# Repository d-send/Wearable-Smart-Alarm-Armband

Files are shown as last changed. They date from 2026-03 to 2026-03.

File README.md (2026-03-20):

# Wearable Smart Alarm Armband (Work in progress)

An Armband designed primaraly for force waking up in the morning using vibration and Electrical stimulation.Uses an android app to communicate via BLE for scheuling and monitering status such as battery capacity.Integrated IMU is used to detect weather the user is awake or sleeping.

## Features
* Wakeup sheduling capability through an android app via BLE
* reminders through vibrations
* two hardware buttons for additional functionalities
* extremely low power consumption
* detachable battery
* tightness adjestable strip (around arm)  

## PCB
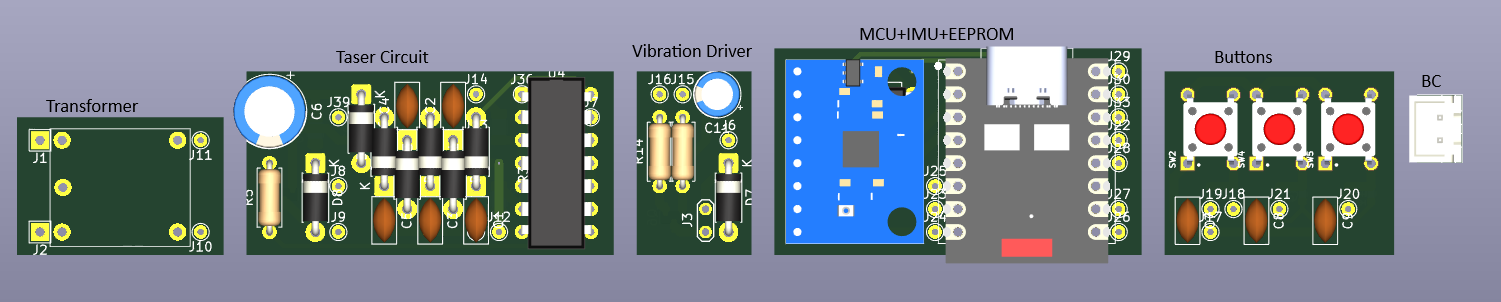
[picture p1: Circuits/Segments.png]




## Finished Armband 
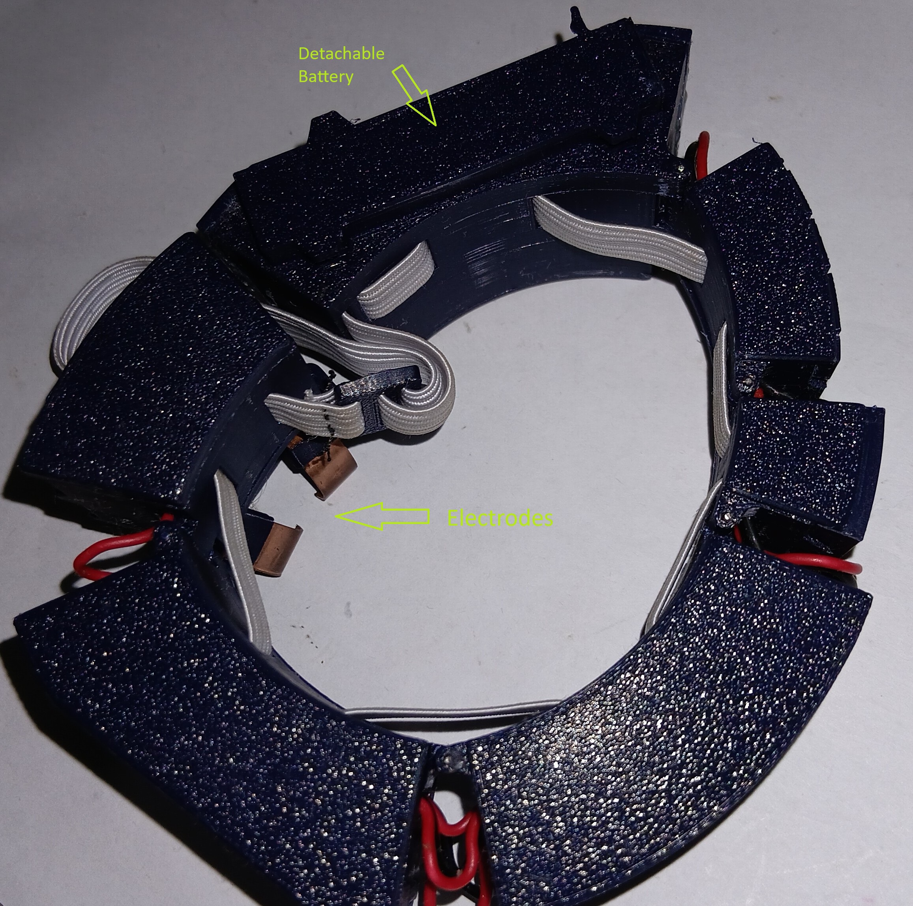
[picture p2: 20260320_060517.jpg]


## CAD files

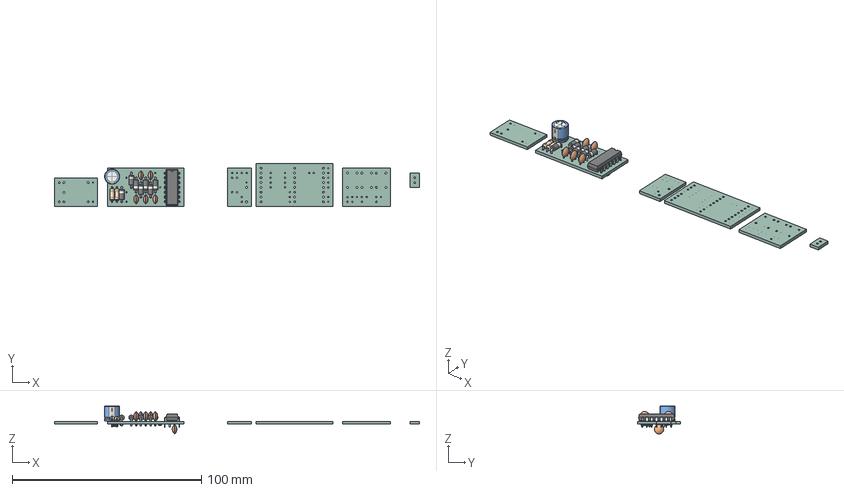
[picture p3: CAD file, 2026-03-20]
Circuits/PCB/Tazer.step
193.0 x 22.9 x 14.8 mm
C_Disc_D5.0mm_W2.5mm_P2.50mm x 6
D_DO-41_SOD81_P7.62mm_Horizontal x 7
R_Axial_DIN0207_L6.3mm_D2.5mm_P7.62mm_Horizontal x 3
DIP-14_W7.62mm
CP_Radial_D8.0mm_P3.80mm
SOT-23
R_1206_3216Metric x 3
R_0603_1608Metric x 2
PCB_V6_PCB_1
PCB_V6_PCB_2
PCB_V6_PCB_3
PCB_V6_PCB_4
PCB_V6_PCB_5
PCB_V6_PCB_6

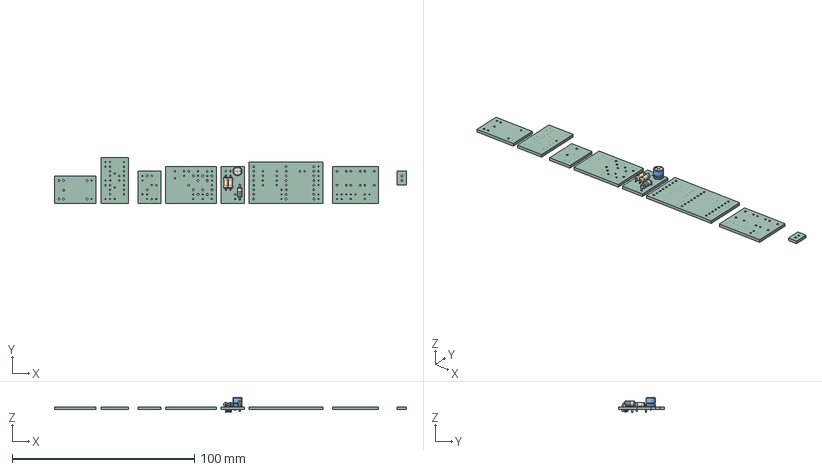
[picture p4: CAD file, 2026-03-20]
Circuits/PCB/VIB_DRIVER.step
193.0 x 25.4 x 8.00 mm
D_DO-41_SOD81_P7.62mm_Horizontal
R_Axial_DIN0207_L6.3mm_D2.5mm_P7.62mm_Horizontal x 2
CP_Radial_D5.0mm_P2.50mm
SOT-23
PCB_V6_PCB_1
PCB_V6_PCB_2
PCB_V6_PCB_3
PCB_V6_PCB_4
PCB_V6_PCB_5
PCB_V6_PCB_6
PCB_V6_PCB_7
PCB_V6_PCB_8

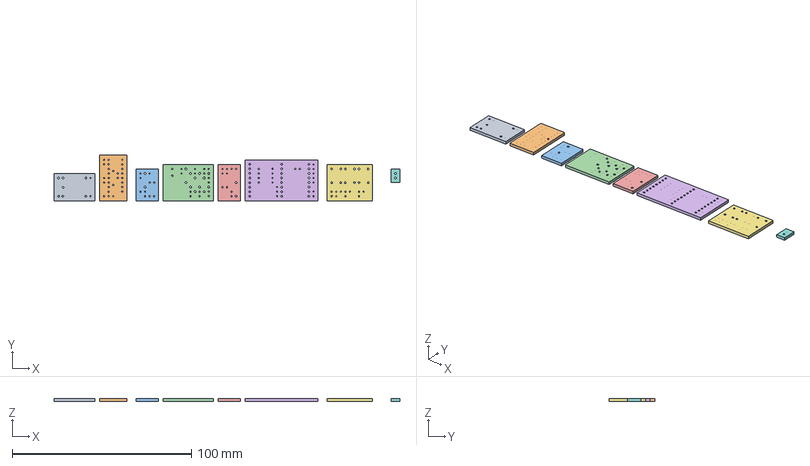
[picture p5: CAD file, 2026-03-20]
Circuits/PCB/Flyback_Transformer.step
193.0 x 25.4 x 1.51 mm
PCB_V6_PCB_1
PCB_V6_PCB_2
PCB_V6_PCB_3
PCB_V6_PCB_4
PCB_V6_PCB_5
PCB_V6_PCB_6
PCB_V6_PCB_7
PCB_V6_PCB_8

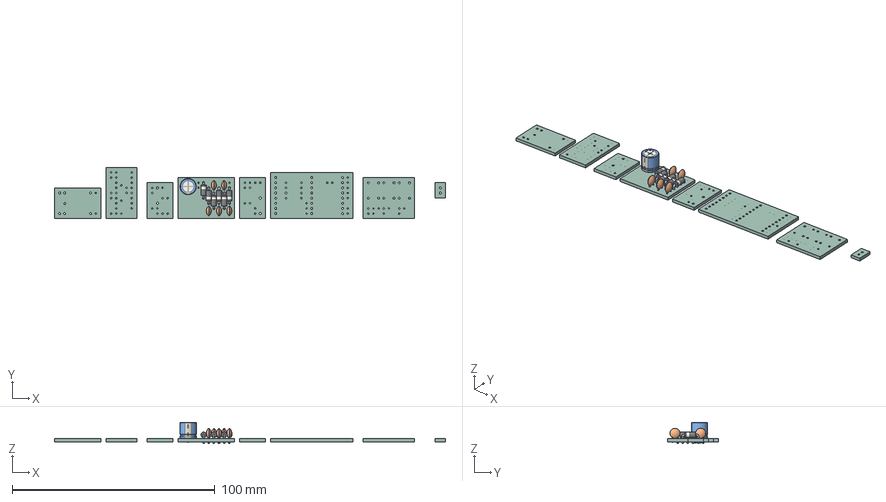
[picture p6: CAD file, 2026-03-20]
Circuits/PCB/Tazer_Charger.step
193.0 x 25.4 x 10.5 mm
C_Disc_D5.0mm_W2.5mm_P2.50mm x 5
D_DO-41_SOD81_P7.62mm_Horizontal x 6
CP_Radial_D8.0mm_P3.80mm
R_0603_1608Metric x 2
PCB_V6_PCB_1
PCB_V6_PCB_2
PCB_V6_PCB_3
PCB_V6_PCB_4
PCB_V6_PCB_5
PCB_V6_PCB_6
PCB_V6_PCB_7
PCB_V6_PCB_8

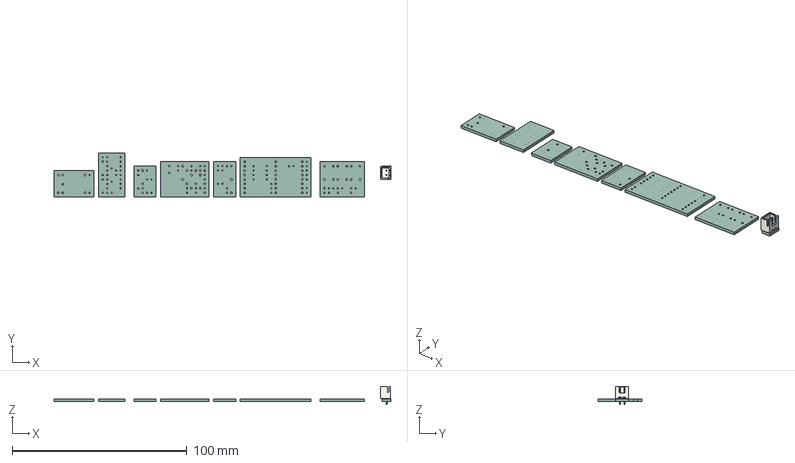
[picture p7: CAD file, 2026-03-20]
Circuits/PCB/Bat_Connector.step
193.0 x 25.4 x 10.4 mm
JST_XH_B2B-XH-A_1x02_P2.50mm_Vertical
PCB_V6_PCB_1
PCB_V6_PCB_2
PCB_V6_PCB_3
PCB_V6_PCB_4
PCB_V6_PCB_5
PCB_V6_PCB_6
PCB_V6_PCB_7
PCB_V6_PCB_8

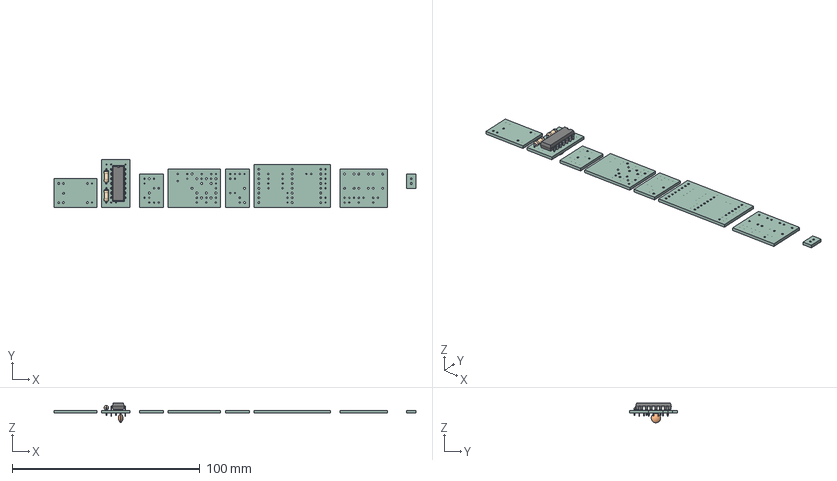
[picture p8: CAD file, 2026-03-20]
Circuits/PCB/Inverter.step
193.0 x 25.4 x 10.5 mm
R_Axial_DIN0207_L6.3mm_D2.5mm_P7.62mm_Horizontal x 3
DIP-14_W7.62mm
C_Disc_D5.0mm_W2.5mm_P2.50mm
PCB_V6_PCB_1
PCB_V6_PCB_2
PCB_V6_PCB_3
PCB_V6_PCB_4
PCB_V6_PCB_5
PCB_V6_PCB_6
PCB_V6_PCB_7
PCB_V6_PCB_8

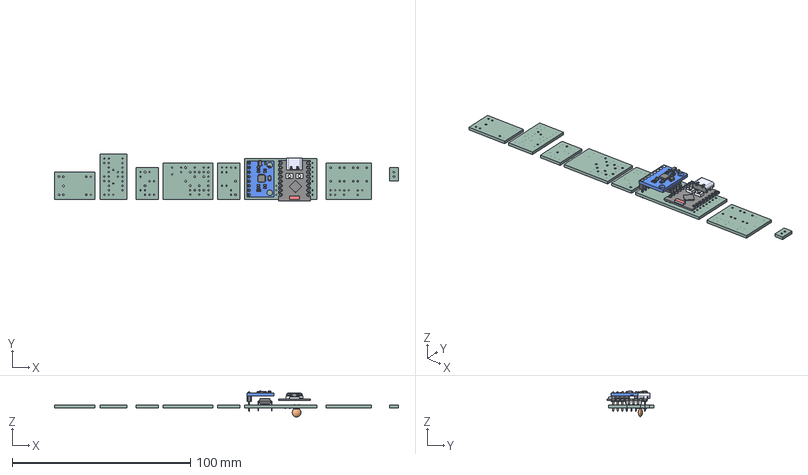
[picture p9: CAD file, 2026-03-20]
Circuits/PCB/MCU_EEPROM.step
193.0 x 26.3 x 14.6 mm
Board_001
SOT25_001
0603 Capacitor_001
0603 Capacitor_002
0603 Capacitor_003
0603 Capacitor_004
0603 Capacitor_005
0603 Capacitor_006
0603 Resistor_001
0603 Resistor_002
0603 Resistor_003
0603 Resistor_004
SM LED_001
Diode 2_001
24 QFN_001
1x8 Male Header_001
DIP-8_W7.62mm
Board c3mini
USB C
components (other)^ESP32-C3 SuperMini
R_0603_1608Metric x 2
R_1206_3216Metric x 2
C_Disc_D5.0mm_W2.5mm_P2.50mm
PCB_V6_PCB_1
PCB_V6_PCB_2
PCB_V6_PCB_3
PCB_V6_PCB_4
PCB_V6_PCB_5
PCB_V6_PCB_6
PCB_V6_PCB_7
PCB_V6_PCB_8

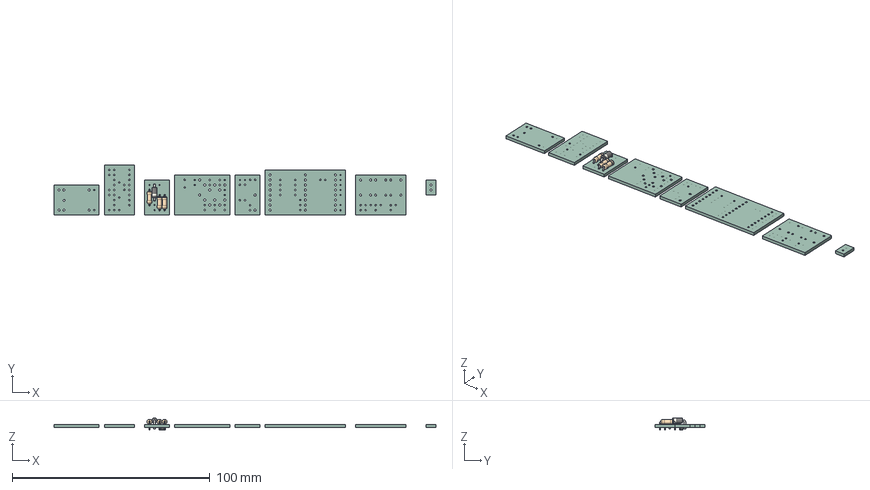
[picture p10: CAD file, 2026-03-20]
Circuits/PCB/Tazer_Discharger.step
193.0 x 25.4 x 6.21 mm
D_DO-41_SOD81_P7.62mm_Horizontal
R_Axial_DIN0207_L6.3mm_D2.5mm_P7.62mm_Horizontal x 3
SOT-23
PCB_V6_PCB_1
PCB_V6_PCB_2
PCB_V6_PCB_3
PCB_V6_PCB_4
PCB_V6_PCB_5
PCB_V6_PCB_6
PCB_V6_PCB_7
PCB_V6_PCB_8

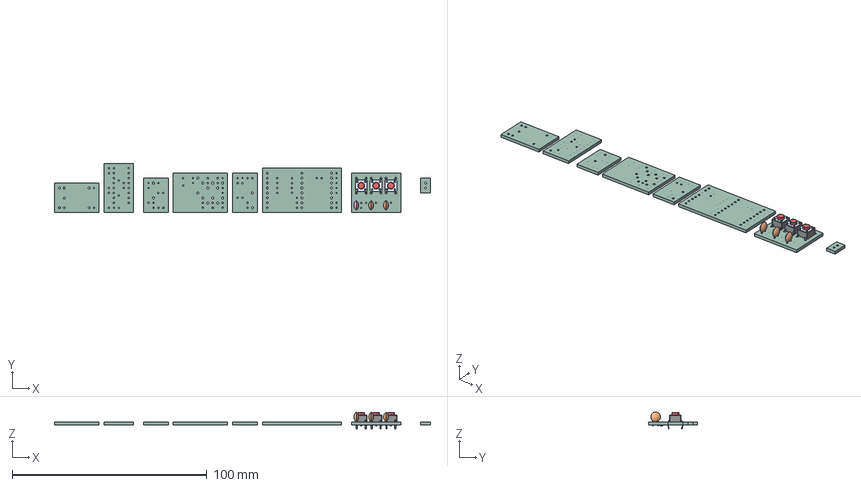
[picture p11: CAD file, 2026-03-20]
Circuits/PCB/Buttons.step
193.0 x 25.4 x 8.61 mm
1825910-6--3DModel-STEP-418109 x 3
C_Disc_D5.0mm_W2.5mm_P2.50mm x 3
R_0603_1608Metric x 6
PCB_V6_PCB_1
PCB_V6_PCB_2
PCB_V6_PCB_3
PCB_V6_PCB_4
PCB_V6_PCB_5
PCB_V6_PCB_6
PCB_V6_PCB_7
PCB_V6_PCB_8

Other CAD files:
Fusion Files/BatteryConnector_Finished.f3d
Fusion Files/Buttons_Finished.f3d
Fusion Files/MCU_Finished.f3d
Fusion Files/MainHousings.f3d
Fusion Files/Tazer_Finished.f3d
Fusion Files/Transformer_Finised.f3d
Fusion Files/Vib_Driver_Finished.f3d

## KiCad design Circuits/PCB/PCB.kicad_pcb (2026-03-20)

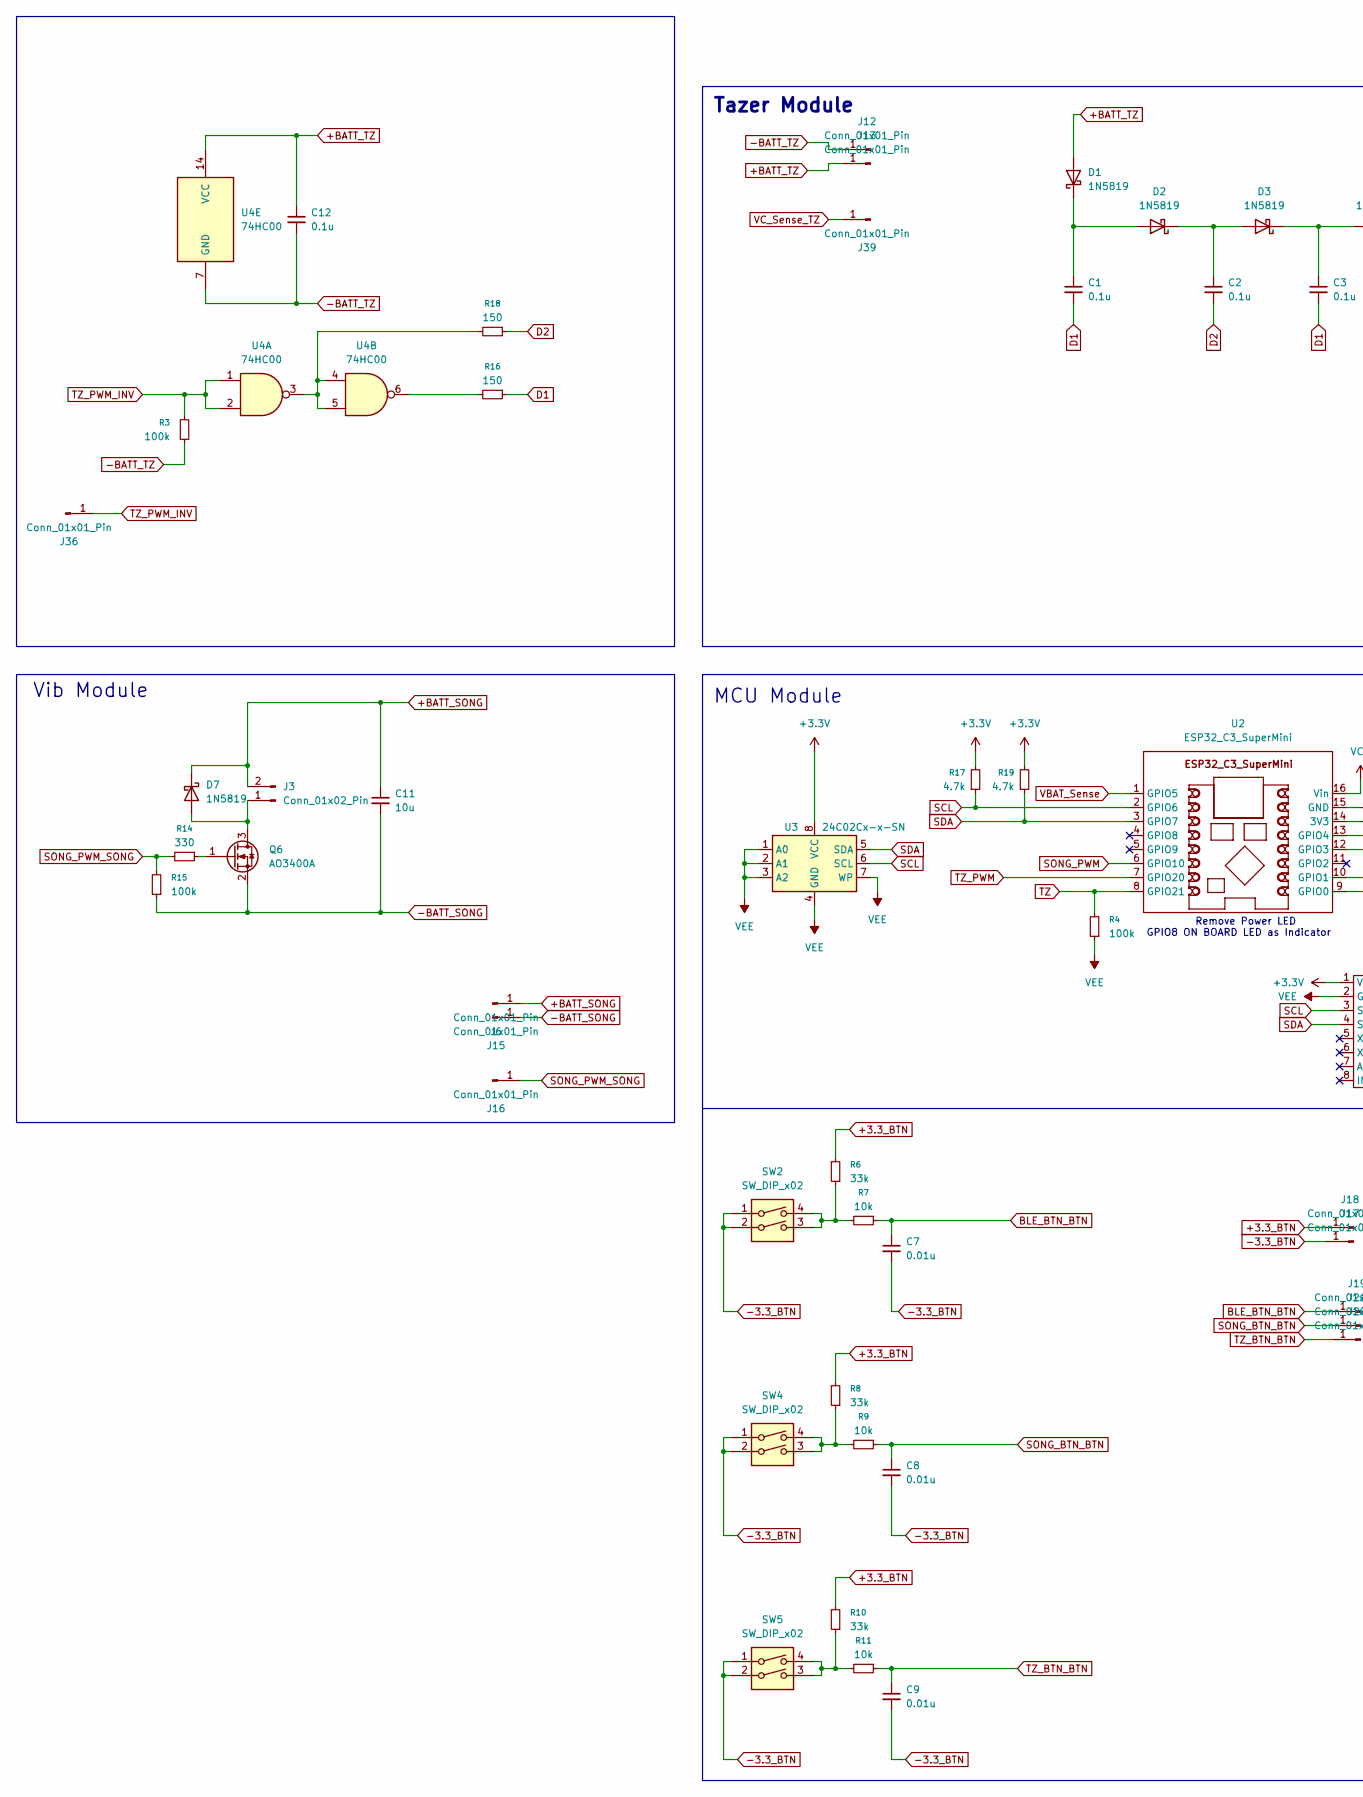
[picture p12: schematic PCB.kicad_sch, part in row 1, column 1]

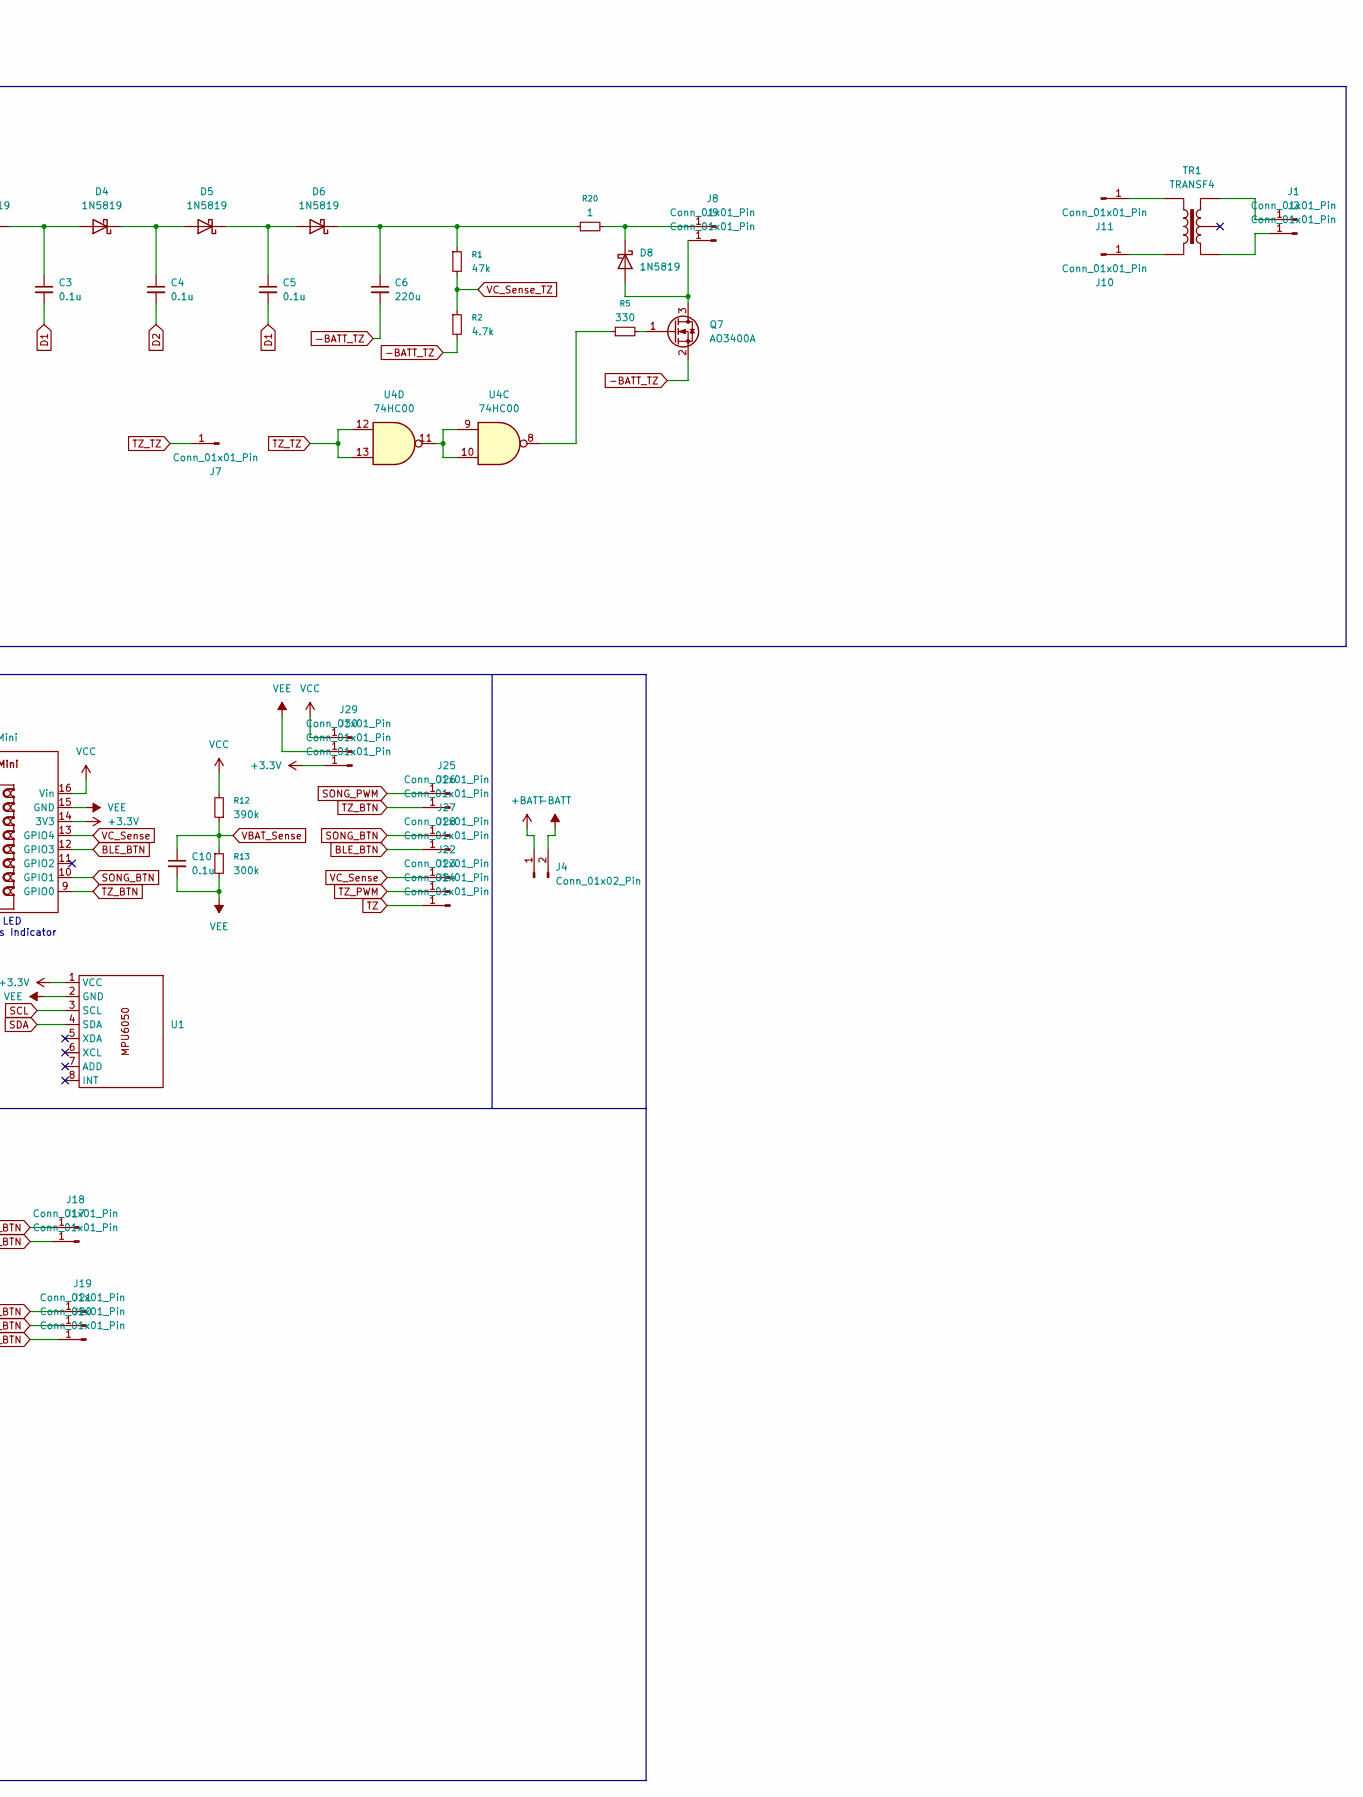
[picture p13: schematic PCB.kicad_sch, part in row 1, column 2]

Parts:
C1, C2, C3, C4, C5, C10, C12: 0.1u; C_Disc_D5.0mm_W2.5mm_P2.50mm
C6: 220u; CP_Radial_D8.0mm_P3.80mm
C7, C8, C9: 0.01u; C_Disc_D5.0mm_W2.5mm_P2.50mm
C11: 10u; CP_Radial_D5.0mm_P2.50mm
D1, D2, D3, D4, D5, D6, D7, D8: 1N5819; D_DO-41_SOD81_P7.62mm_Horizontal
J1, J2: Conn_01x01_Pin; TestPoint_THTPad_2.0x2.0mm_Drill1.0mm
J3: Conn_01x02_Pin; TestPoint_2Pads_Pitch2.54mm_Drill0.8mm
J4: Conn_01x02_Pin; JST_XH_B2B-XH-A_1x02_P2.50mm_Vertical
J6, J7, J8, J9, J10, J11, J12, J13, J15, J16, J17, J18, J19, J20, J21, J22, J23, J24, J25, J26, J27, J28, J29, J30, J33, J36, J39: Conn_01x01_Pin; TestPoint_THTPad_D1.5mm_Drill0.7mm
Q6, Q7: AO3400A; SOT-23
R1: 47k; R_0603_1608Metric
R2, R17, R19: 4.7k; R_0603_1608Metric
R3, R15: 100k; R_Axial_DIN0207_L6.3mm_D2.5mm_P7.62mm_Horizontal
R4: 100k; R_Axial_DIN0207_L6.3mm_D2.5mm_P10.16mm_Horizontal
R5, R14: 330; R_Axial_DIN0207_L6.3mm_D2.5mm_P7.62mm_Horizontal
R6, R8, R10: 33k; R_0603_1608Metric
R7, R9, R11: 10k; R_0603_1608Metric
R12: 390k; R_1206_3216Metric
R13: 300k; R_1206_3216Metric
R16, R18: 150; R_1206_3216Metric
R20: 1; R_1206_3216Metric
SW2, SW4, SW5: SW_DIP_x02; DPDT_Switch
TR1: TRANSF4; 5pin Flyback Transformer
U1: MPU6050_Module
U2: ESP32_C3_SuperMini
U3: 24C02Cx-x-SN; DIP-8_W7.62mm
U4: 74HC00; DIP-14_W7.62mm

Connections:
+3.3V: J33.1, R17.2, R19.2, U1.1 (VCC), U2.14 (3V3), U3.8 (VCC)
+3.3_BTN: J18.1, R6.2, R8.2, R10.2
+BATT: J4.1
+BATT_SONG: C11.1, D7.1 (K), J3.2, J6.1
+BATT_TZ: C12.1, D1.2 (A), J13.1, U4.14 (VCC)
-3.3_BTN: C7.2, C8.2, C9.2, J17.1, SW2.1, SW2.2, SW4.1, SW4.2, SW5.1, SW5.2
-BATT: J4.2
-BATT_SONG: C11.2, J15.1, Q6.2 (S), R15.1
-BATT_TZ: C6.2, C12.2, J12.1, Q7.2 (S), R2.2, R3.1, U4.7 (GND)
BLE_BTN: J28.1, U2.12 (GPIO3)
BLE_BTN_BTN: C7.1, J19.1, R7.1
D1: C1.2, C3.2, C5.2, R16.1; also elsewhere on the board
D2: C2.2, C4.2, R18.1; also elsewhere on the board
unnamed: C1.1, D1.1 (K), D2.2 (A)
unnamed: C2.1, D2.1 (K), D3.2 (A)
unnamed: C3.1, D3.1 (K), D4.2 (A)
unnamed: C4.1, D4.1 (K), D5.2 (A)
unnamed: C5.1, D5.1 (K), D6.2 (A)
unnamed: C6.1, D6.1 (K), R1.1, R20.1
unnamed: D7.2 (A), J3.1, Q6.3 (D)
unnamed: D8.2 (A), J9.1, Q7.3 (D)
unnamed: D8.1 (K), J8.1, R20.2
unnamed: J1.1, TR1.3
unnamed: J2.1, TR1.1
unnamed: J10.1, TR1.5
unnamed: J11.1, TR1.4
unnamed: Q6.1 (G), R14.1
unnamed: Q7.1 (G), R5.2
unnamed: R5.1, U4.8
unnamed: R6.1, R7.2, SW2.3, SW2.4
unnamed: R8.1, R9.2, SW4.3, SW4.4
unnamed: R10.1, R11.2, SW5.3, SW5.4
unnamed: R16.2, U4.6
unnamed: R18.2, U4.3, U4.4, U4.5
unnamed: U4.9, U4.10, U4.11
SCL: R17.1, U1.3 (SCL), U2.2 (GPIO6), U3.6 (SCL)
SDA: R19.1, U1.4 (SDA), U2.3 (GPIO7), U3.5 (SDA)
SONG_BTN: J27.1, U2.10 (GPIO1)
SONG_BTN_BTN: C8.1, J21.1, R9.1
SONG_PWM: J25.1, U2.6 (GPIO10)
SONG_PWM_SONG: J16.1, R14.2, R15.2
TZ: J24.1, R4.2, U2.8 (GPIO21)
TZ_BTN: J26.1, U2.9 (GPIO0)
TZ_BTN_BTN: C9.1, J20.1, R11.1
TZ_PWM: J23.1, U2.7 (GPIO20)
TZ_PWM_INV: J36.1, R3.2, U4.1, U4.2
TZ_TZ: J7.1, U4.12, U4.13
VBAT_Sense: C10.1, R12.1, R13.1, U2.1 (GPIO5)
VCC: J29.1, R12.2, U2.16 (Vin)
VC_Sense: J22.1, U2.13 (GPIO4)
VC_Sense_TZ: J39.1, R1.2, R2.1
VEE: C10.2, J30.1, R4.1, R13.2, U1.2 (GND), U2.15 (GND), U3.1 (A0), U3.2 (A1), U3.3 (A2), U3.4 (GND), U3.7 (WP)

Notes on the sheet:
GPIO8 ON BOARD LED as Indicator
Remove Power LED
MCU Module
Vib Module
Tazer Module

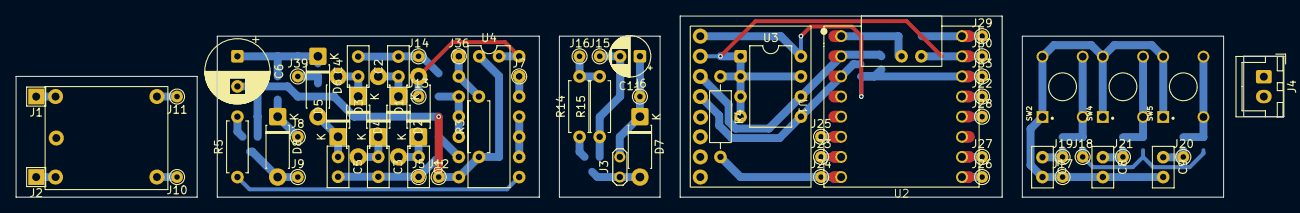
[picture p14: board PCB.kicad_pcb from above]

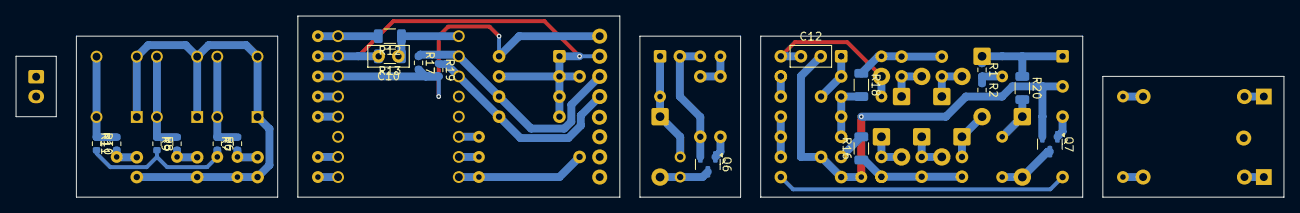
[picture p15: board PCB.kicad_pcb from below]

Board: 2 copper layers, 160.0 x 22.9 mm, 83 parts (19 on the bottom side), 50 nets.

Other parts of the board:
J5, J14: Conn_01x01_Pin; TestPoint_THTPad_D1.5mm_Drill0.7mm

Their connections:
D1: J5.1; also elsewhere on the board
D2: J14.1; also elsewhere on the board

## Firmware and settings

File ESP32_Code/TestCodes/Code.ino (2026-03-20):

#include <Wire.h>


#define R_TOP 47000.0
#define R_BOTTOM 4700.0
#define ADC_REF 3.3
#define ADC_MAX 4095.0
#define VC_Sense 4
#define VBat_Sense 3
#define LED_Builtin 8

#define D_PWM 20
const int VC_Set = 15;
bool Dpwm_Enabled = true;

#define TZ_BTN 0
#define SONG_BTN 1

#define TZ 21

#define Song_PWM 10

#define SCL_PIN 6
#define SDA_PIN 7

#define EEPROM_ADDR 0x50   // 24C16 base address



void eepromWrite(uint16_t addr, uint8_t data)
{
  Wire.beginTransmission(EEPROM_ADDR | ((addr >> 8) & 0x07));
  Wire.write(addr & 0xFF);
  Wire.write(data);
  Wire.endTransmission();
  delay(5);
}

uint8_t eepromRead(uint16_t addr)
{
  Wire.beginTransmission(EEPROM_ADDR | ((addr >> 8) & 0x07));
  Wire.write(addr & 0xFF);
  Wire.endTransmission();

  Wire.requestFrom(EEPROM_ADDR | ((addr >> 8) & 0x07), 1);
  return Wire.read();
}

float readBatteryVoltage(uint8_t ADCpin,float R_top,float R_bottom)
{
  int adc = analogRead(ADCpin);
  float v = (adc / ADC_MAX) * ADC_REF;
  return v * ((R_top + R_bottom) / R_bottom);
}

volatile bool triggerPulse = false;
volatile uint32_t pulseWidth_us = 200;   // Change pulse width here

void IRAM_ATTR gpioInterrupt()
{
  // Interrupt fires on falling edge
  triggerPulse = true;
}

void setup() {
  // put your setup code here, to run once:
  Serial.begin(115200);
  
  pinMode(SONG_BTN,INPUT);
  pinMode(VC_Sense,INPUT);
  pinMode(TZ,OUTPUT);
  pinMode(LED_Builtin,OUTPUT);
  pinMode(Song_PWM,OUTPUT);
  pinMode(D_PWM,OUTPUT);
  ledcAttach(D_PWM,10000,8);
  pinMode(TZ_BTN,INPUT);
  attachInterrupt(digitalPinToInterrupt(TZ_BTN),
                  gpioInterrupt,
                  FALLING);

  digitalWrite(TZ,LOW);
  digitalWrite(LED_Builtin,HIGH);
  digitalWrite(Song_PWM,LOW);

  Wire.begin(SDA_PIN, SCL_PIN);

  ledcWrite(D_PWM, 128);
}

void loop() {
  // put your main code here, to run repeatedly:

  uint8_t v = eepromRead(0);
  uint8_t u = eepromRead(56);
  Serial.print(v);
  Serial.print("\t");
  Serial.print(u);
  Serial.print("\t");

  float vc = readBatteryVoltage(VC_Sense,47000.0,4700.0);

  if(vc > 18.0)
  {
    digitalWrite(LED_Builtin,LOW);
    ledcDetach(D_PWM);
    digitalWrite(D_PWM,LOW);
    Dpwm_Enabled = false;
  }
  else
  {
    if((vc < 8.0) && (Dpwm_Enabled == false))
    {
      Dpwm_Enabled = true;
      ledcAttach(D_PWM,10000,8);
      ledcWrite(D_PWM, 128);
      digitalWrite(LED_Builtin,HIGH);

    }
  }

  float vbat = readBatteryVoltage(VBat_Sense,390000.0,300000.0);
  vbat = (5*vbat/5.78);

  Serial.print(vc);
  Serial.print("\t");
  Serial.print(vbat);
  Serial.print("\t");

  if(digitalRead(SONG_BTN) == 0)
  { 
    digitalWrite(Song_PWM,HIGH);
  }
  else
  {
    digitalWrite(Song_PWM,LOW);
  }

  if (triggerPulse) 
  {
    triggerPulse = false;

    digitalWrite(TZ, HIGH);
    delayMicroseconds(pulseWidth_us);
    digitalWrite(TZ, LOW);
  }


  Serial.print(digitalRead(TZ_BTN));
  Serial.print("\t");

  
  Serial.print(digitalRead(SONG_BTN));
  Serial.println("\t");


}
